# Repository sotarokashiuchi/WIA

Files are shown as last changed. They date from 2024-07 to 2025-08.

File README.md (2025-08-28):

# WIA (Who Is Absent)
WIAは、学生証を用いて出席確認を自動化し、手間やミスを削減するための出席管理システムです。パソコンやスマートフォンなど、すべての端末から操作可能で、オフラインで完結するのが特徴です。

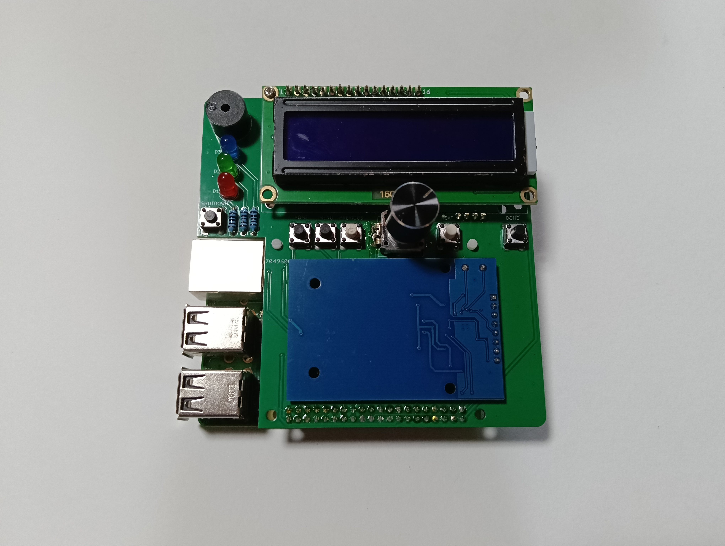
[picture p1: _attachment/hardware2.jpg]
hardware
  
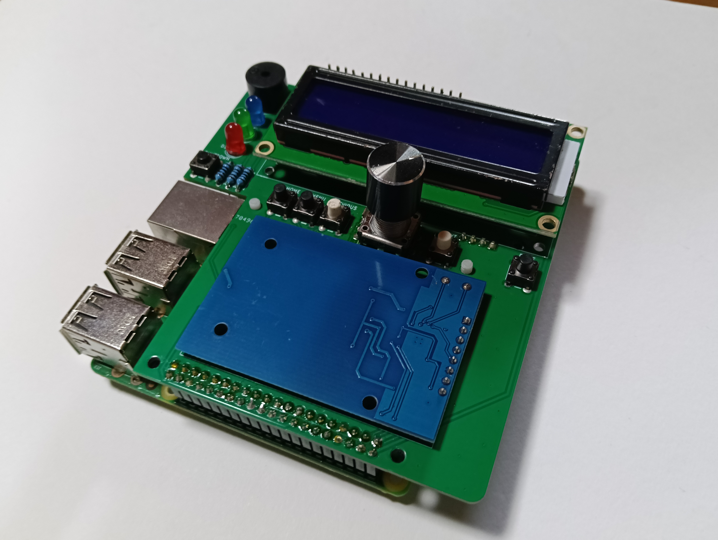
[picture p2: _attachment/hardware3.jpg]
hardware


## 特徴
- 学生証を利用した出席確認
- 高速かつ正確な一括出席管理
- オフラインで完結（電源さえあれば動作可能）
- Webブラウザから操作可能（端末を問わず）

## 主な機能
- 学生証の登録
- 出席簿の作成と管理
- 出席確認
- 手動入力対応
- CSV形式での出力
- 時刻同期機能
- デーモン化による自動起動
- シャットダウン機能

## システム構成
システム構成

## デモンストレーション
### ユーザ登録
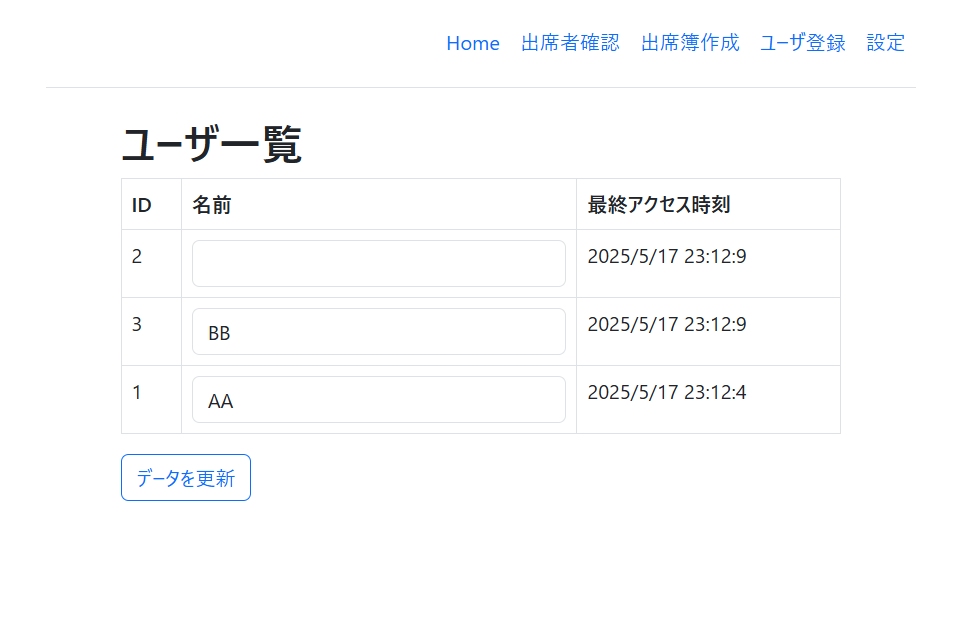
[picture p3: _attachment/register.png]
ユーザ登録


### 出席簿作成
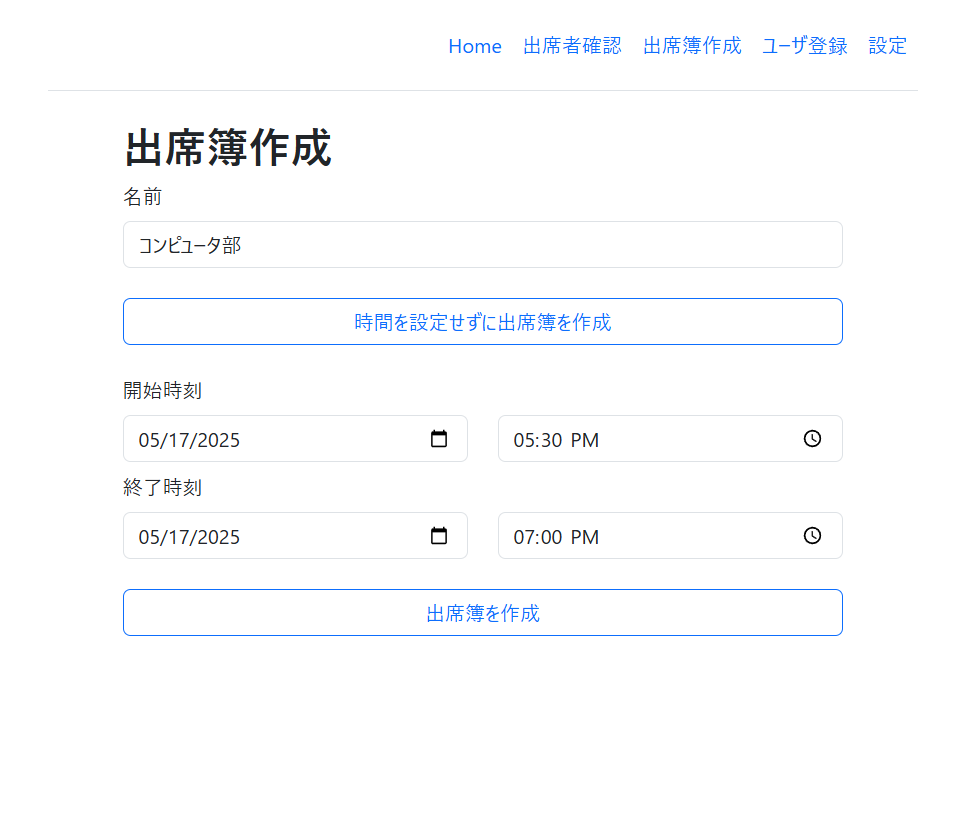
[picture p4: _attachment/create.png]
出席簿作成


### 出席簿
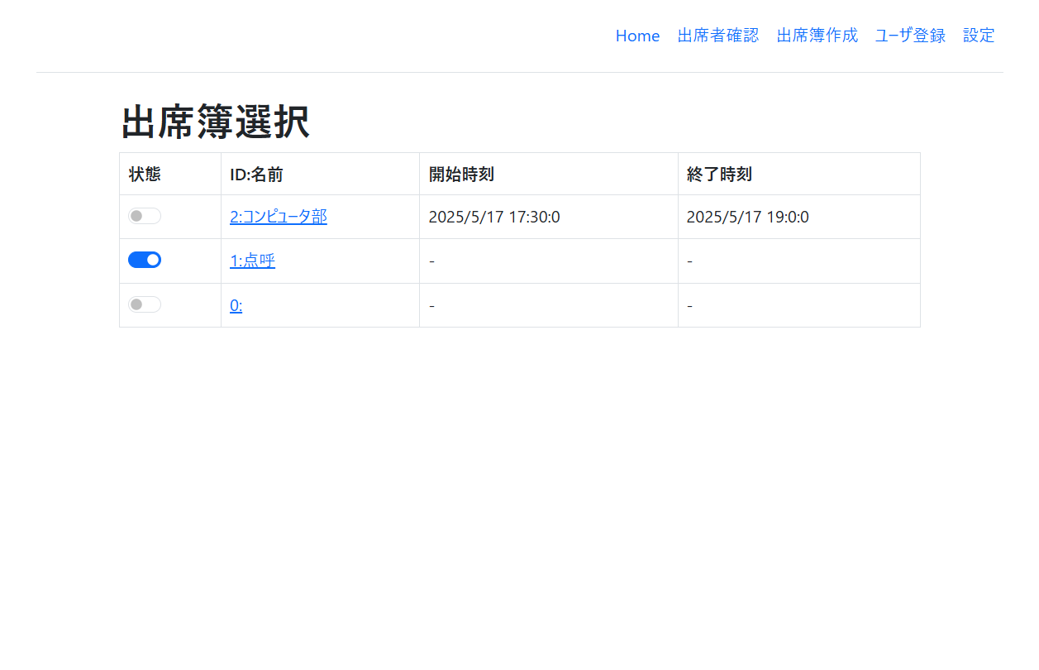
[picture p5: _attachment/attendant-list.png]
出席簿一覧


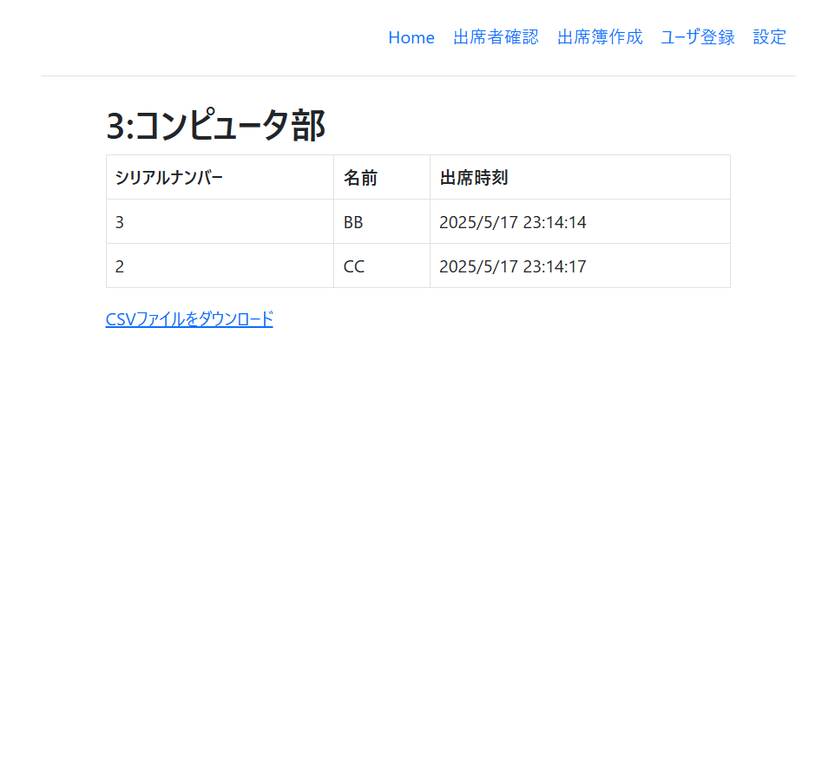
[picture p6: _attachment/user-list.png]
出席者一覧


## Setup
```shell
# copy systemd file
cd ACPj/systemd/systemd
sudo cp HttpEcho.service NFCTouch.service /lib/systemd/system/

# start demon
sudo systemctl daemon-reload
sudo systemctl enable NFCTouch.service
sudo systemctl enable HttpEcho.service

# setting shutdown pin
sudo vi /boot/config.txt
# add to /boot/config.txt
dtoverlay=gpio-shutdown,gpio_pin=4,debounce=2000

# reboot
sudo reboot
```

## Remote Desktop
1. ラズベリーパイとパソコンをEthernetケーブルで接続する
2. パソコンの有線ケーブルに静的IPアドレス`169.254.26.5`, マスクを`255.255.255.0`を割り当てる
3. SSH接続(Tera Term 5を使うと良い)または、RDP接続(windowsならmstscを LinuxならRemminaを使うと良い)を行う
   - ラズベリーパイのIPアドレス`169.254.26.30`
   - Username denki
   - Password password

## 部品
| 名称 | 数量 |
| --- | --- |
| Raspberry Pi 2B | 1 |
| M2*5~7 | 8 |
| M2スペーサ | 4 |
| ピンヘッダ20*2 | 1 |
| RFID-RC522 | 1 |
| M3*9~12 | 4 |
| I2C transport LCD | 1 |
| M3*12~15 | 4 |
| M3ボルト | 8 |
| RTC | 1 |
| M2*8~11 | 3 |
| M2ボルト | 3 |
| RotaryEncoder_Switch  | 1 |
| 抵抗 130Ω | 3 |
| スイッチ | 5 or 6 |
| LED(RED, BLUE, GREEN) | 3 |
| ブザー | 1 |

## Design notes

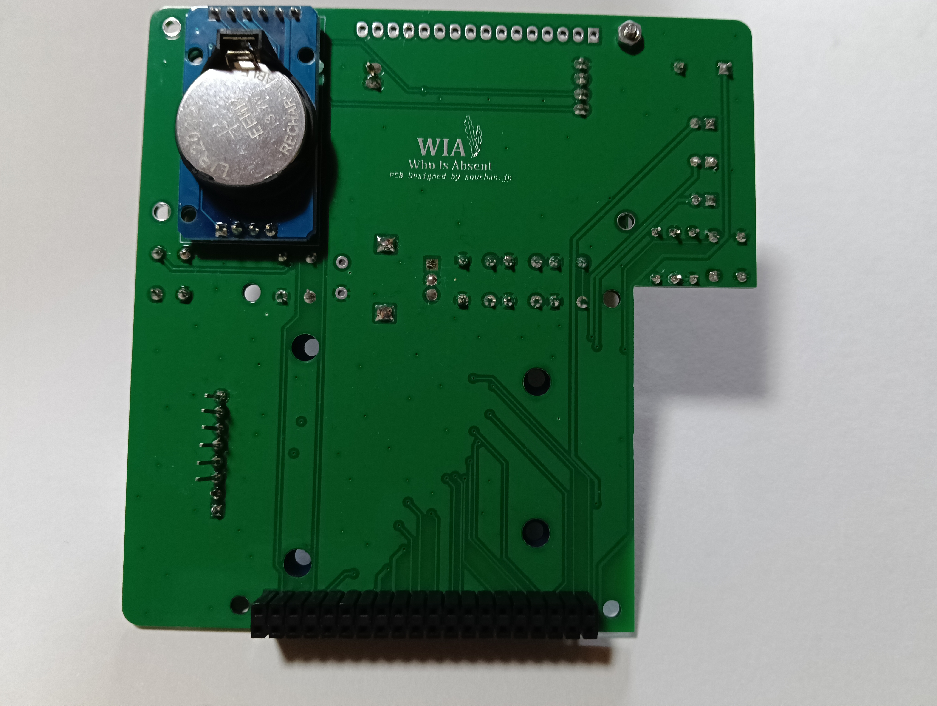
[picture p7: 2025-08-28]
_attachment/hardware1.jpg

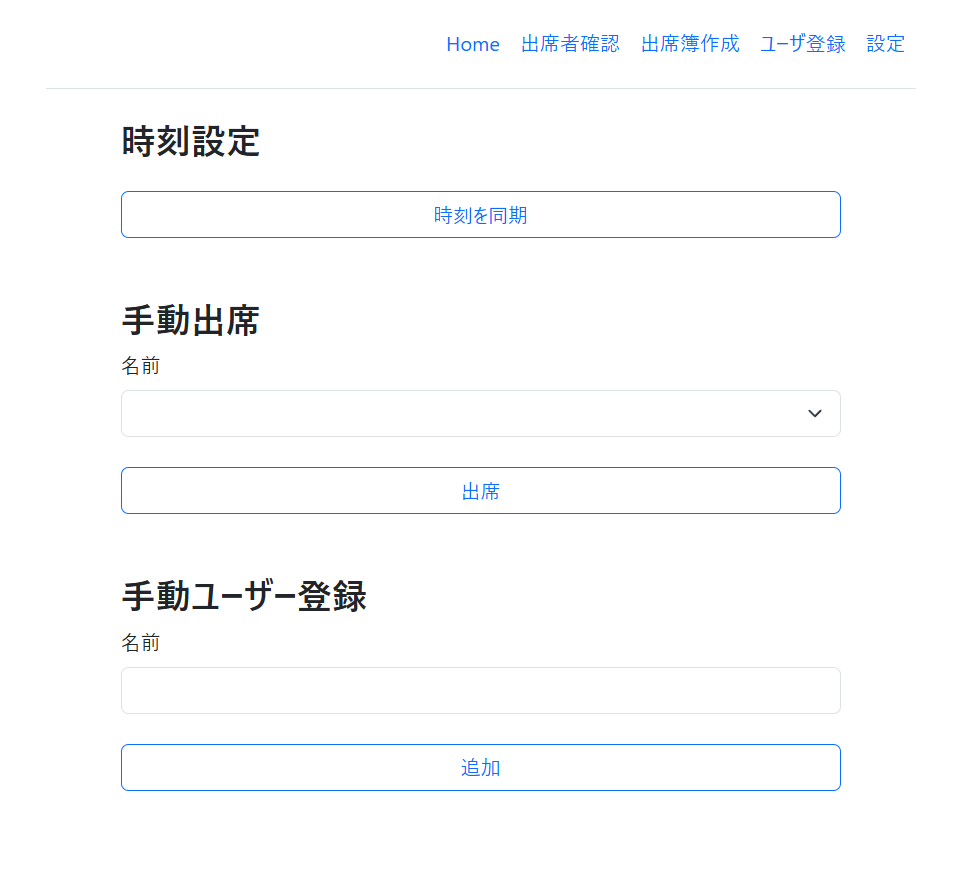
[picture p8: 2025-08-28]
_attachment/setting.png

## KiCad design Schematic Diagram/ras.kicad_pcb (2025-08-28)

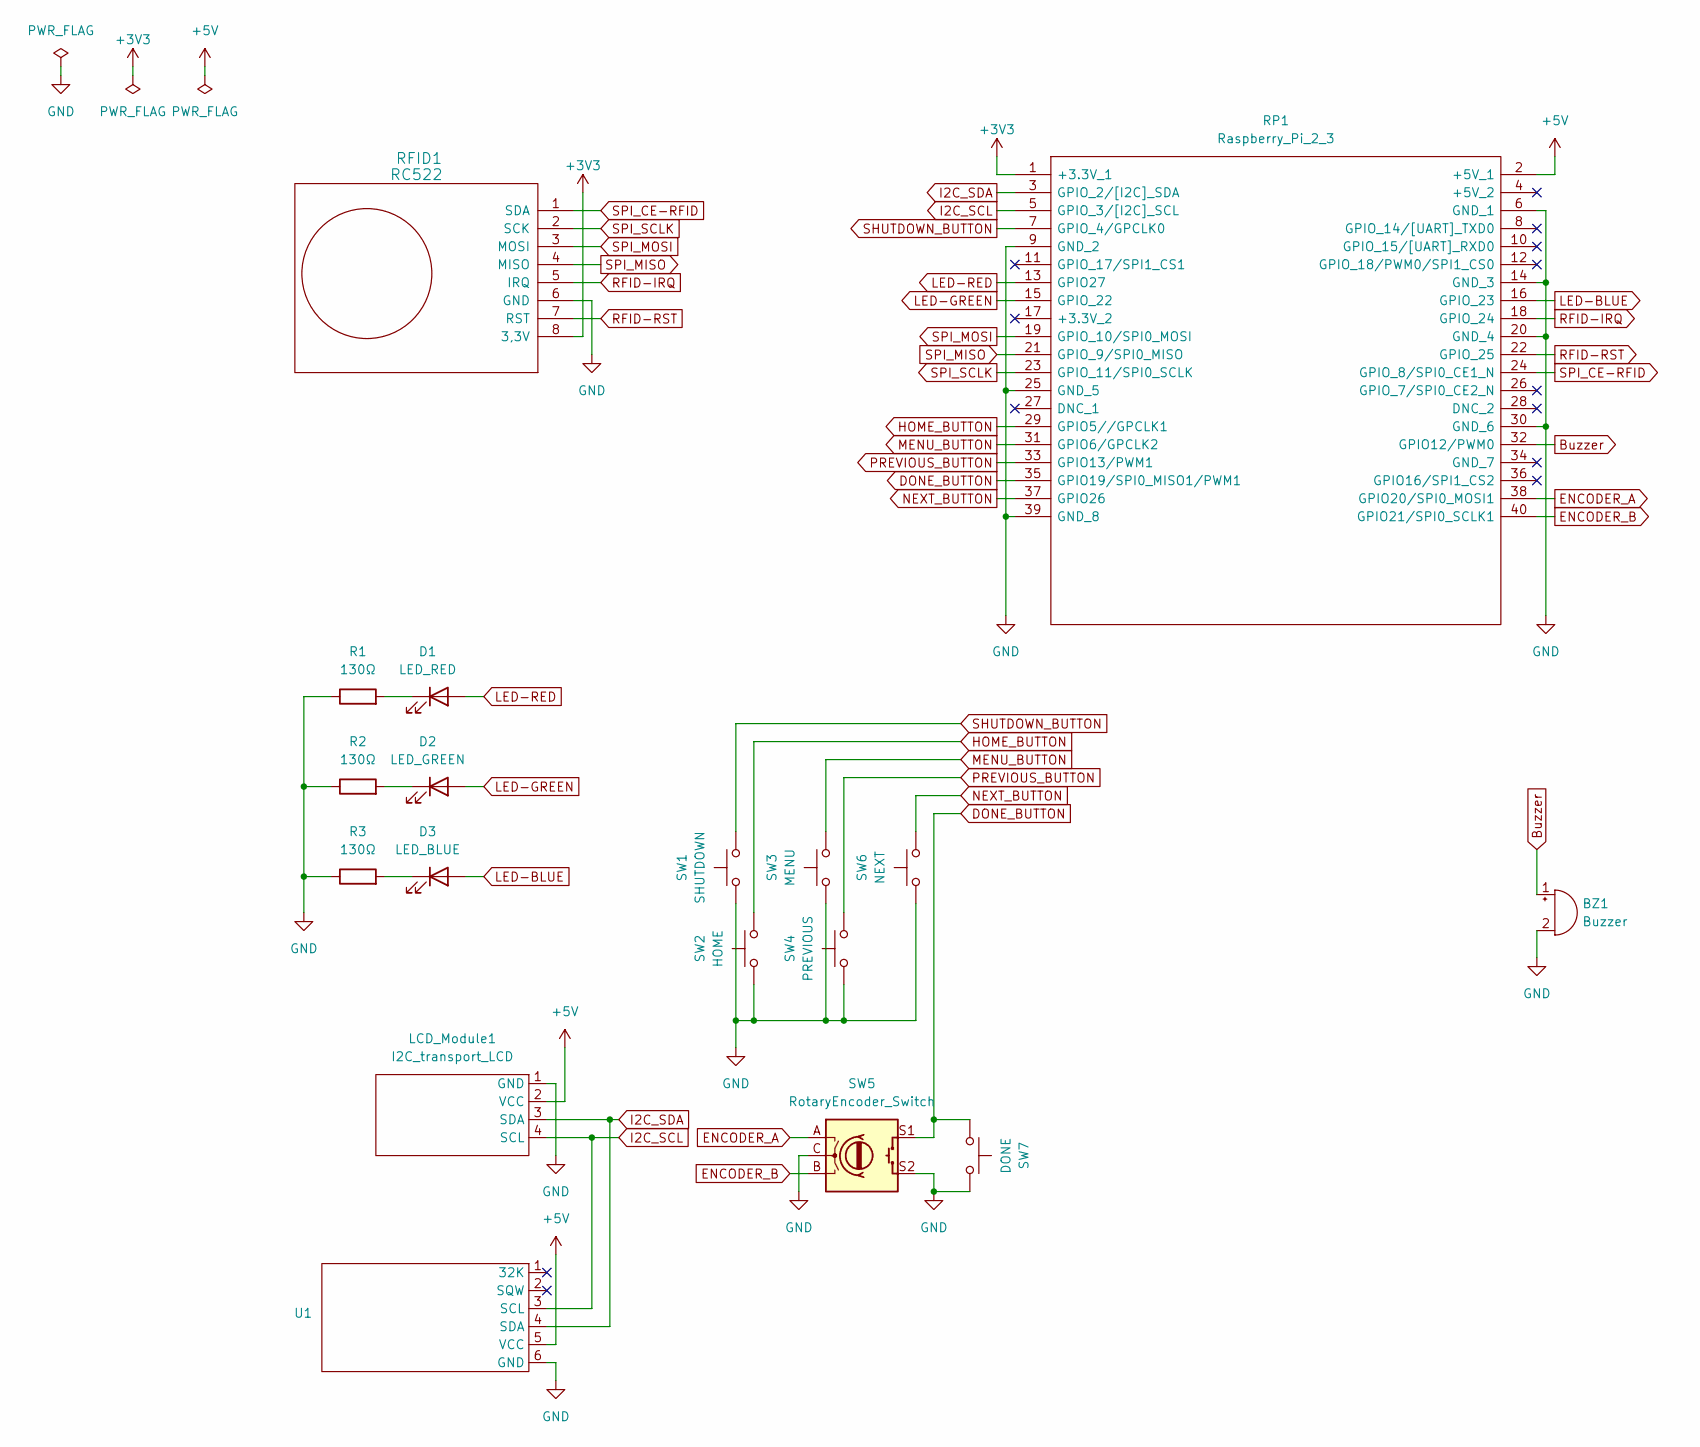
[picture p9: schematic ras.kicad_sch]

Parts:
BZ1: Buzzer; Buzzer_12x9.5RM7.6
D1: LED_RED; LED_D5.0mm
D2: LED_GREEN; LED_D5.0mm
D3: LED_BLUE; LED_D5.0mm
LCD_Module1: I2C_transport_LCD; WC1602A
R1, R2, R3: 130Ω; R_Axial_DIN0207_L6.3mm_D2.5mm_P7.62mm_Horizontal
RFID1: RC522; RFID-RC522
RP1: Raspberry_Pi_2_3; raspberrypi3; Manufacturer_Part_Number Raspberry Pi 2 or 3
SW1: SHUTDOWN; SW_PUSH_6mm
SW2: HOME; SW_PUSH_6mm
SW3: MENU; SW_PUSH_6mm
SW4: PREVIOUS; SW_PUSH_6mm
SW5: RotaryEncoder_Switch; RotaryEncoder_Alps_EC12E-Switch_Vertical_H20mm
SW6: NEXT; SW_PUSH_6mm
SW7: DONE; SW_PUSH_6mm
U1: DS3231M

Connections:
+3V3: RFID1.8 (3,3V), RP1.1 (+3.3V_1)
+5V: LCD_Module1.2 (VCC), RP1.2 (+5V_1), U1.5 (VCC)
Buzzer: BZ1.1 (-), RP1.32 (GPIO12/PWM0)
DONE_BUTTON: RP1.35 (GPIO19/SPI0_MISO1/PWM1), SW5.S1, SW7.1
ENCODER_A: RP1.38 (GPIO20/SPI0_MOSI1), SW5.A
ENCODER_B: RP1.40 (GPIO21/SPI0_SCLK1), SW5.B
GND: BZ1.2 (+), LCD_Module1.1 (GND), R1.1, R2.1, R3.1, RFID1.6 (GND), RP1.6 (GND_1), RP1.9 (GND_2), RP1.14 (GND_3), RP1.20 (GND_4), RP1.25 (GND_5), RP1.30 (GND_6), RP1.39 (GND_8), SW1.1, SW2.1, SW3.1, SW4.1, SW5.C, SW5.S2, SW6.1, SW7.2, U1.6 (GND)
HOME_BUTTON: RP1.29 (GPIO5//GPCLK1), SW2.2
I2C_SCL: LCD_Module1.4 (SCL), RP1.5 (GPIO_3/[I2C]_SCL), U1.3 (SCL)
I2C_SDA: LCD_Module1.3 (SDA), RP1.3 (GPIO_2/[I2C]_SDA), U1.4 (SDA)
LED-BLUE: D3.2 (A), RP1.16 (GPIO_23)
LED-GREEN: D2.2 (A), RP1.15 (GPIO_22)
LED-RED: D1.2 (A), RP1.13 (GPIO27)
MENU_BUTTON: RP1.31 (GPIO6/GPCLK2), SW3.2
NEXT_BUTTON: RP1.37 (GPIO26), SW6.2
unnamed: D1.1 (K), R1.2
unnamed: D2.1 (K), R2.2
unnamed: D3.1 (K), R3.2
PREVIOUS_BUTTON: RP1.33 (GPIO13/PWM1), SW4.2
RFID-IRQ: RFID1.5 (IRQ), RP1.18 (GPIO_24)
RFID-RST: RFID1.7 (RST), RP1.22 (GPIO_25)
SHUTDOWN_BUTTON: RP1.7 (GPIO_4/GPCLK0), SW1.2
SPI_CE-RFID: RFID1.1 (SDA), RP1.24 (GPIO_8/SPI0_CE1_N)
SPI_MISO: RFID1.4 (MISO), RP1.21 (GPIO_9/SPI0_MISO)
SPI_MOSI: RFID1.3 (MOSI), RP1.19 (GPIO_10/SPI0_MOSI)
SPI_SCLK: RFID1.2 (SCK), RP1.23 (GPIO_11/SPI0_SCLK)

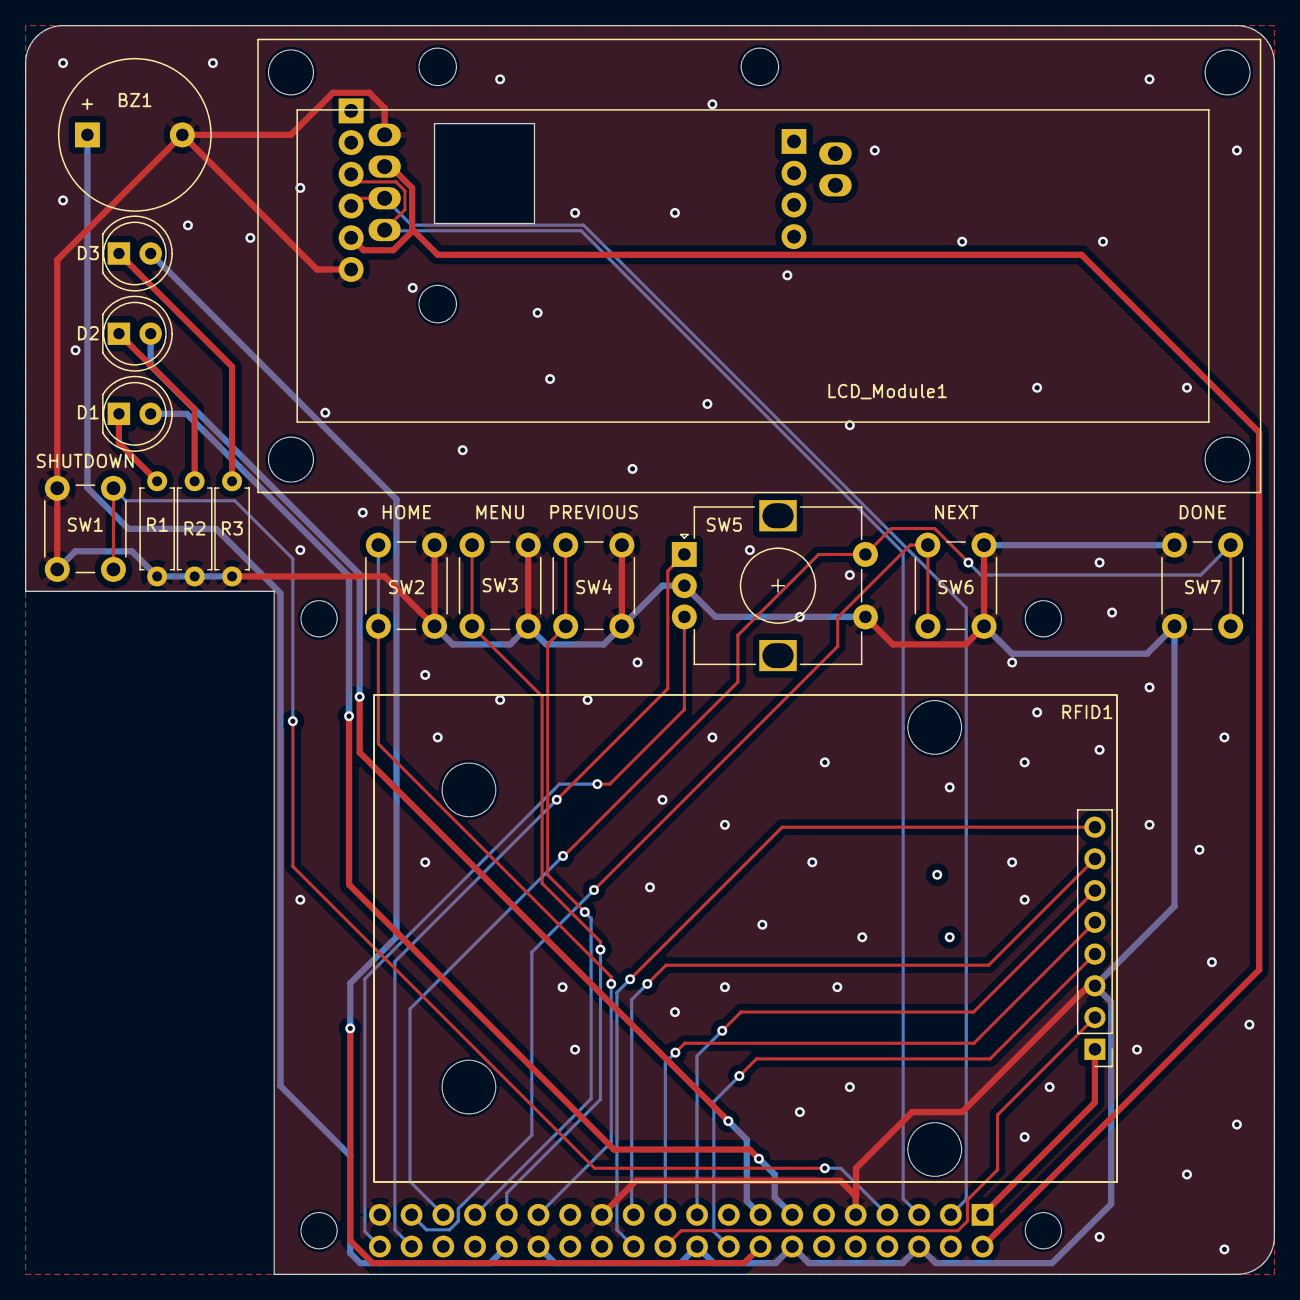
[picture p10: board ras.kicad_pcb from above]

Board: 2 copper layers, 100.0 x 100.0 mm, 18 parts (1 on the bottom side), 26 nets.

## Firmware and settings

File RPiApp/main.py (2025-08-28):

import RPi.GPIO as GPIO
import requests
import time
import i2clcda as lcd
from pirc522 import RFID
import tone
import encoder as ENCODER
import subprocess

HIGH = 1
LOW = 0
LED_GREEN = 22
LED_RED = 27
LED_BLUE = 23
BUZZER = 12
ROTARY_ENCODER_A = 20
ROTARY_ENCODER_B = 21
HOME_BUTTON = 5
MENU_BUTTON = 6
PREVIOUS_BUTTON = 13
DONE_BUTTON = 19
NEXT_BUTTON = 26

SW_ON = 0
SW_OFF = 1

rdr = RFID(pin_rst=25, pin_irq=24, pin_mode=GPIO.BCM)
buzzerPWM = tone.Tone(BUZZER)
encoder = ENCODER.Encoder(ROTARY_ENCODER_A, ROTARY_ENCODER_B)

def initialize():
    GPIO.setmode(GPIO.BCM)
    GPIO.setwarnings(False)
    GPIO.setup(LED_RED, GPIO.OUT, initial=GPIO.LOW)
    GPIO.setup(LED_GREEN, GPIO.OUT, initial=GPIO.LOW)
    GPIO.setup(LED_BLUE, GPIO.OUT, initial=GPIO.LOW)
    GPIO.setup(ROTARY_ENCODER_A, GPIO.IN, pull_up_down=GPIO.PUD_UP)
    GPIO.setup(ROTARY_ENCODER_B, GPIO.IN, pull_up_down=GPIO.PUD_UP)
    GPIO.setup(MENU_BUTTON, GPIO.IN, pull_up_down=GPIO.PUD_UP)
    GPIO.setup(NEXT_BUTTON, GPIO.IN, pull_up_down=GPIO.PUD_UP)
    GPIO.setup(PREVIOUS_BUTTON, GPIO.IN, pull_up_down=GPIO.PUD_UP)
    GPIO.setup(DONE_BUTTON, GPIO.IN, pull_up_down=GPIO.PUD_UP)
    GPIO.setup(HOME_BUTTON, GPIO.IN, pull_up_down=GPIO.PUD_UP)

    lcd.lcd_init()
    lcd.lcd_string("> Completed", lcd.LCD_LINE_1)
    lcd.lcd_string("> Initialize!!", lcd.LCD_LINE_2)


def finalize():
    GPIO.cleanup()
    rdr.cleanup()
    lcd.lcd_byte(0x01, lcd.LCD_CMD)
    buzzerPWM.destroy()
    return

def requestNFCToch(serialNumber):
    response = requests.post(
            "http://localhost:1234/nfc/touch",
            headers={"Content-Type": "application/x-www-form-urlencoded"},
            data={"serialNumber": serialNumber}
    )

    return response.json()["name"]

def readTagUID():
    rdr.wait_for_tag(1)
    (error, tag_type) = rdr.request()
    if not error:
        (error, uid) = rdr.anticoll()
        if not error:
            return str(uid)

def wait_sw_off(SW):
    while GPIO.input(SW)==SW_ON:
        pass
    return

def menu():
    lcd_menu = [
                    [
                        ">Attendance",
                        " Time  WiFi"
                    ],[
                        " Attendance",
                        ">Time  WiFi"
                    ],[
                        " Attendance",
                        " Time >WiFi"
                    ]
                ]
    lcd_menu_index=0

    while GPIO.input(DONE_BUTTON)!=SW_ON:
        lcd.lcd_string(lcd_menu[lcd_menu_index][0], lcd.LCD_LINE_1)
        lcd.lcd_string(lcd_menu[lcd_menu_index][1], lcd.LCD_LINE_2)
        lcd.lcd_display_on()
        if GPIO.input(HOME_BUTTON)==SW_ON:
            wait_sw_off(HOME_BUTTON)
            return
        if GPIO.input(NEXT_BUTTON)==SW_ON:
            lcd_menu_index=lcd_menu_index+1
            if lcd_menu_index >= 3:
                lcd_menu_index=2
            wait_sw_off(NEXT_BUTTON)
        if GPIO.input(PREVIOUS_BUTTON)==SW_ON:
            lcd_menu_index=lcd_menu_index-1
            if lcd_menu_index < 0:
                lcd_menu_index=0
            wait_sw_off(PREVIOUS_BUTTON)
    
    wait_sw_off(DONE_BUTTON)

    if lcd_menu_index==0:
        set_attendance()
    elif lcd_menu_index==1:
        set_time()
    elif lcd_menu_index==2:
        get_wifi()

def set_attendance():
    pass

def set_time():
    lcd_time = [
              # "YYYY/MM/DD HH:MM",
                "   ^            ",
                "      ^         ",
                "         ^      ",
                "            ^   ",
                "               ^",
            ]
    lcd_time_index=0
    lcd_count=250

    now_time = subprocess.check_output(["sudo", "hwclock", "-r"])
    now_time = now_time.decode('utf-8')
    setting_time = [
            int(now_time[0:4]),
            int(now_time[5:7]),
            int(now_time[8:10]),
            int(now_time[11:13]),
            int(now_time[14:16])
        ]


    while GPIO.input(DONE_BUTTON)!=0:
        if lcd_count==250:
            lcd.lcd_string(str(setting_time[0]).zfill(4)+"/"+str(setting_time[1]             ).zfill(2)+"/"+str(setting_time[2]).zfill(2)+" "+str(setting_time[3]).zfill(2)+"             :"+str(setting_time[4]).zfill(2), lcd.LCD_LINE_1)
            lcd.lcd_string(lcd_time[lcd_time_index], lcd.LCD_LINE_2)
            # lcd.lcd_display_on()
            lcd_count=0
        else:
            lcd_count=lcd_count+1

        if GPIO.input(HOME_BUTTON)==0:
            wait_sw_off(HOME_BUTTON)
            return
        if GPIO.input(NEXT_BUTTON)==0:
            lcd_time_index=lcd_time_index+1
            if lcd_time_index >= 5:
                lcd_time_index=4
            wait_sw_off(NEXT_BUTTON)
        if GPIO.input(PREVIOUS_BUTTON)==0:
            lcd_time_index=lcd_time_index-1
            if lcd_time_index < 0:
                lcd_time_index=0
            wait_sw_off(PREVIOUS_BUTTON)

        encoder.set(setting_time[lcd_time_index])
        data = encoder.read()
        if lcd_time_index==1:
            if data>12:
                data=1
            if data<=0:
                data=12
        elif lcd_time_index==2:
            if data>31:
                data=1
            if data<=0:
                data=31
        elif lcd_time_index==3:
            if data>23:
                data=0
            if data<0:
                data=23
        elif lcd_time_index==4:
            if data>59:
                data=0
            if data<0:
                data=59
        setting_time[lcd_time_index] = data

    subprocess.call(["sudo", "date", "-s", str(setting_time[0]).zfill(4)+"/"+str             (setting_time[1]).zfill(2)+"/"+str(setting_time[2]).zfill(2)+" "+str(setting_tim             e[3]).zfill(2)+":"+str(setting_time[4]).zfill(2)])
    subprocess.call(["sudo", "hwclock", "-w"])

def get_wifi():
    pass

def main():
    serialNumber = ""
    name = ""
    oldSerialNumber = ""
    oldTimeStanp = 0
    while True:
        if GPIO.input(MENU_BUTTON)==SW_ON:
            menu()

        # NFC読み取り処理
        oldSerialNumber = serialNumber
        oldTimeStanp = time.time()
        serialNumber = readTagUID()
        if oldSerialNumber == serialNumber and time.time()-oldTimeStanp < 0.01:
            time.sleep(0.1)
            continue
        
        name = requestNFCToch(serialNumber)
        lcd.lcd_display_off()
        if name == "":
            # 名前の未登録
            buzzerPWM.beep(440)
            lcd.lcd_string("Warning", lcd.LCD_LINE_1)
            lcd.lcd_string("Not Registered", lcd.LCD_LINE_2)
            lcd.lcd_display_on()
            GPIO.output(BUZZER, HIGH)
            GPIO.output(LED_RED, HIGH)
            time.sleep(0.05)
            buzzerPWM.none()
        else:
            # 正常処理
            requestNFCToch(serialNumber)
            buzzerPWM.beep(2000)
            lcd.lcd_string("Completed!", lcd.LCD_LINE_1)
            lcd.lcd_string(name, lcd.LCD_LINE_2)
            lcd.lcd_display_on()
            GPIO.output(BUZZER, HIGH)
            GPIO.output(LED_BLUE, HIGH)
            time.sleep(0.05)
            buzzerPWM.none()
        
        time.sleep(0.75)
        GPIO.output(LED_GREEN, LOW)
        GPIO.output(LED_BLUE, LOW)
        GPIO.output(LED_RED, LOW)
        lcd.lcd_init()
    return

if __name__ == '__main__':
    try:
        initialize()
        main()
    except KeyboardInterrupt:
        pass
    finally:
        finalize()

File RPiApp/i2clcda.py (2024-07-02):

# _____ _____ _____ __ __ _____ _____
# |	 |   __|	 |  |  |	 |	 |
# |  |  |__   |  |  |_   _|  |  |  |  |
# |_____|_____|_____| |_| |_____|_____|
#
# Project Tutorial Url:http://osoyoo.com/?p=1031
#
import smbus
import time
import unicodedata

# | I2C_ADDR | RS (LCD_CHR or LCD_CMD) | D7 D6 D5 D4 E EN R/W RS
#									  | D3 D2 D1 D0 E EN R/W RS

# Define some device parameters
I2C_ADDR = 0x27  # I2C device address, if any error, change this address to 0x3f
LCD_WIDTH = 16  # Maximum characters per line

# Define some device constants
LCD_CHR = 1  # Mode - Sending data
LCD_CMD = 0  # Mode - Sending command

LCD_LINE_1 = 0x80  # LCD RAM address for the 1st line
LCD_LINE_2 = 0xC0  # LCD RAM address for the 2nd line
LCD_LINE_3 = 0x94  # LCD RAM address for the 3rd line
LCD_LINE_4 = 0xD4  # LCD RAM address for the 4th line

LCD_BACKLIGHT = 0x08  # On
# LCD_BACKLIGHT = 0x00  # Off

ENABLE = 0b00000100  # Enable bit

# Timing constants
E_PULSE = 0.0005
E_DELAY = 0.0005

# Open I2C interface
# bus = smbus.SMBus(0)  # Rev 1 Pi uses 0
bus = smbus.SMBus(1)  # Rev 2 Pi uses 1


def lcd_init():
    # Initialise display
    lcd_byte(0x33, LCD_CMD)  # 110011 Initialise
    lcd_byte(0x32, LCD_CMD)  # 110010 Initialise
    lcd_byte(0x06, LCD_CMD)  # 000110 Cursor move direction
    lcd_byte(0x0C, LCD_CMD)  # 001100 Display On,Cursor Off, Blink Off
    lcd_byte(0x28, LCD_CMD)  # 101000 Data length, number of lines, font size
    lcd_byte(0x01, LCD_CMD)  # 000001 Clear display
    time.sleep(E_DELAY)


def lcd_byte(bits, mode):
    # Send byte to data pins
    # bits = the data
    # mode = 1 for data
    #		0 for command

    # D7 D6 D5 D4 LCD_BACKLIGHT _ _ mode
    bits_high = mode | (bits & 0xF0) | LCD_BACKLIGHT
    # D3 D2 D1 D0 LCD_BACKLIGHT _ _ mode
    bits_low = mode | ((bits << 4) & 0xF0) | LCD_BACKLIGHT

    # High bits
    lcd_toggle_enable(bits_high)

    # Low bits
    lcd_toggle_enable(bits_low)

def lcd_toggle_enable(bits):
    # Toggle enable
    # D7 D6 D5 D4 LCD_BACKLIGHT 1 _ mode
    bus.write_byte(I2C_ADDR, (bits | ENABLE))
    time.sleep(E_PULSE)
    # D7 D6 D5 D4 LCD_BACKLIGHT 0 _ mode
    bus.write_byte(I2C_ADDR, (bits & ~ENABLE))
    time.sleep(E_DELAY)
    
def lcd_display_off():
    lcd_byte(0b00001010, LCD_CMD)

def lcd_display_on():
    lcd_byte(0b00001110, LCD_CMD)

def lcd_string(message, line):
    lcd_byte(line, LCD_CMD)
    i = 0
    j = 0
    while i < LCD_WIDTH:
        j += 1
        if len(message) < j:
            # 余白を空白文字で埋める
            lcd_byte(ord(" "), LCD_CHR)
            i += 1
            continue
        
        character = message[j-1]
        if unicodedata.east_asian_width(character) in "Na":
            lcd_byte(ord(character), LCD_CHR)
            i += 1
            continue
        
        if character in "パピプペポ":
            if character == "パ":
                lcd_byte(0b11001010, LCD_CHR)
            elif character == "ピ":
                lcd_byte(0b11001011, LCD_CHR)
            elif character == "プ":
                lcd_byte(0b11001100, LCD_CHR)
            elif character == "ペ":
                lcd_byte(0b11001101, LCD_CHR)
            elif character == "ポ":
                lcd_byte(0b11001110, LCD_CHR)
            lcd_byte(0b11011111, LCD_CHR)
            i += 2
            continue

        if character in "ガギグゲゴザジズゼゾダヂヅデドバビブベボ":
            if character == "ガ":
                    lcd_byte(0b10110110, LCD_CHR)
            elif character == "ギ":
                lcd_byte(0b10110111, LCD_CHR)
            elif character == "グ":
                lcd_byte(0b10111000, LCD_CHR)
            elif character == "ゲ":
                lcd_byte(0b10111001, LCD_CHR)
            elif character == "ゴ":
                lcd_byte(0b10111010, LCD_CHR)
            elif character == "ザ":
                lcd_byte(0b10111011, LCD_CHR)
            elif character == "ジ":
                lcd_byte(0b10111100, LCD_CHR)
            elif character == "ズ":
                lcd_byte(0b10111101, LCD_CHR)
            elif character == "ゼ":
                lcd_byte(0b10111110, LCD_CHR)
            elif character == "ゾ":
                lcd_byte(0b10111111, LCD_CHR)
            elif character == "ダ":
                lcd_byte(0b11000000, LCD_CHR)
            elif character == "ヂ":
                lcd_byte(0b11000001, LCD_CHR)
            elif character == "ヅ":
                lcd_byte(0b11000010, LCD_CHR)
            elif character == "デ":
                lcd_byte(0b11000011, LCD_CHR)
            elif character == "ド":
                lcd_byte(0b11000100, LCD_CHR)
            elif character == "バ":
                lcd_byte(0b11001010, LCD_CHR)
            elif character == "ビ":
                lcd_byte(0b11001011, LCD_CHR)
            elif character == "ブ":
                lcd_byte(0b11001100, LCD_CHR)
            elif character == "ベ":
                lcd_byte(0b11001101, LCD_CHR)
            elif character == "ボ":
                lcd_byte(0b11001110, LCD_CHR)
            lcd_byte(0b11011110, LCD_CHR)
            i += 2
            continue
        
        if character in "アイウエオカキクケコサシスセソタチツテトナニヌネノハヒフヘホマミムメモヤユヨラリルレロワン":
            if character == "ア":
                lcd_byte(0b10110001, LCD_CHR)
            elif character == "イ":
                lcd_byte(0b10110010, LCD_CHR)
            elif character == "ウ":
                lcd_byte(0b10110011, LCD_CHR)
            elif character == "エ":
                lcd_byte(0b10110100, LCD_CHR)
            elif character == "オ":
                lcd_byte(0b10110101, LCD_CHR)
            elif character == "カ":
                lcd_byte(0b10110110, LCD_CHR)
            elif character == "キ":
                lcd_byte(0b10110111, LCD_CHR)
            elif character == "ク":
                lcd_byte(0b10111000, LCD_CHR)
            elif character == "ケ":
                lcd_byte(0b10111001, LCD_CHR)
            elif character == "コ":
                lcd_byte(0b10111010, LCD_CHR)
            elif character == "サ":
                lcd_byte(0b10111011, LCD_CHR)
            elif character == "シ":
                lcd_byte(0b10111100, LCD_CHR)
            elif character == "ス":
                lcd_byte(0b10111101, LCD_CHR)
            elif character == "セ":
                lcd_byte(0b10111110, LCD_CHR)
            elif character == "ソ":
                lcd_byte(0b10111111, LCD_CHR)
            elif character == "タ":
                lcd_byte(0b11000000, LCD_CHR)
            elif character == "チ":
                lcd_byte(0b11000001, LCD_CHR)
            elif character == "ツ":
                lcd_byte(0b11000010, LCD_CHR)
            elif character == "テ":
                lcd_byte(0b11000011, LCD_CHR)
            elif character == "ト":
                lcd_byte(0b11000100, LCD_CHR)
            elif character == "ナ":
                lcd_byte(0b11000101, LCD_CHR)
            elif character == "ニ":
                lcd_byte(0b11000110, LCD_CHR)
            elif character == "ヌ":
                lcd_byte(0b11000111, LCD_CHR)
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

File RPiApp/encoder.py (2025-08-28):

import RPi.GPIO as GPIO
import time

class Encoder:
    def __init__(self, encoder_a, encoder_b):
        self.counter = 0
        self.AstateOld = 1
        self.BstateOld = 1
        self.RotaryEncoderA = encoder_a
        self.RotaryEncoderB = encoder_b

    def read(self, sleep_time=0.001):
        Astate = GPIO.input(self.RotaryEncoderA)
        Bstate = GPIO.input(self.RotaryEncoderB)

        if Astate == 1 and self.AstateOld == 0:
            self.BstateOld = Bstate

            if self.AstateOld == 0 and self.BstateOld == 0:
                self.counter += 1
            elif self.AstateOld == 0 and self.BstateOld == 1:
                self.counter -= 1

            print("counter  = " + str(self.counter))

        self.AstateOld = Astate
        self.BstateOld = Bstate

        time.sleep(sleep_time)
        return self.counter

    def set(self, value=0):
        self.counter = value

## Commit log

2024-04-27 add lib of raspberrypi
2024-04-27 set RC522
    [ras.kicad_pcb, ras.kicad_sch]
2024-04-27 I2C transport LCD
2024-04-27 put RC522
    [ras.kicad_sch]
2024-04-27 put LED
    [ras.kicad_sch]
2024-04-27 put buzzer
    [ras.kicad_sch]
2024-05-14 抵抗値変更
    [ras.kicad_sch]
2024-05-20 LED and BUZZER
2024-05-20 add comment of I2C
    comment
2024-05-20 LCD カタカナ
2024-05-27 LCD カタカナ動作確認
2024-07-02 update Schematic Diagram
    [ras.kicad_sch]
2024-07-02 fix bug of lcd.string()
    [i2clcda.py]
2024-07-02 時間外の出席簿を有効にできないように制限
2024-07-02 NFCカードが一度話された場合のみ値を更新
2024-07-02 add reset and sample
2024-07-02 add shutdown switch close #6
    [ras.kicad_sch]
2025-04-02 update kicad before 9.0 after 8.0
    [ras.kicad_pcb, ras.kicad_sch]
2025-04-17 update ras and vertify RFID and LED
    [ras.kicad_sch]
2025-04-17 verify I2C
    [ras.kicad_sch]
2025-04-17 vertify encoder and button
    [ras.kicad_sch]
2025-04-21 check ERC
    [ras.kicad_sch]
2025-05-02 create fp-lib and fp-table
    [ras.kicad_sch]
2025-05-02 fix fp
    [ras.kicad_sch]
2025-05-02 display parts
    [ras.kicad_pcb]
2025-05-03 add logo
    [ras.kicad_pcb]
2025-05-09 pass DRC checks
    [ras.kicad_pcb, ras.kicad_sch]
2025-05-16 fix PCB design (closed #7)
    [ras.kicad_pcb]
